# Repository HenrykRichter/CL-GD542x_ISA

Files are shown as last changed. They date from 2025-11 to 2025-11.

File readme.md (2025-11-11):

# Project  Cirrus Logic 542x ISA video card
This project is a fork of [542x_ISA](https://github.com/matt1187/542x_ISA) with some tweaks
and additions to the PCB. Notable changes compared to original project:
- made room on PCB to place the RAMs in SMT sockets
- added Monitor ID option (static or by attached Monitor)

Remaking from Cirrus Logic Databook  "CL-GD542X_Technical_Reference_Manual_Jan1994"
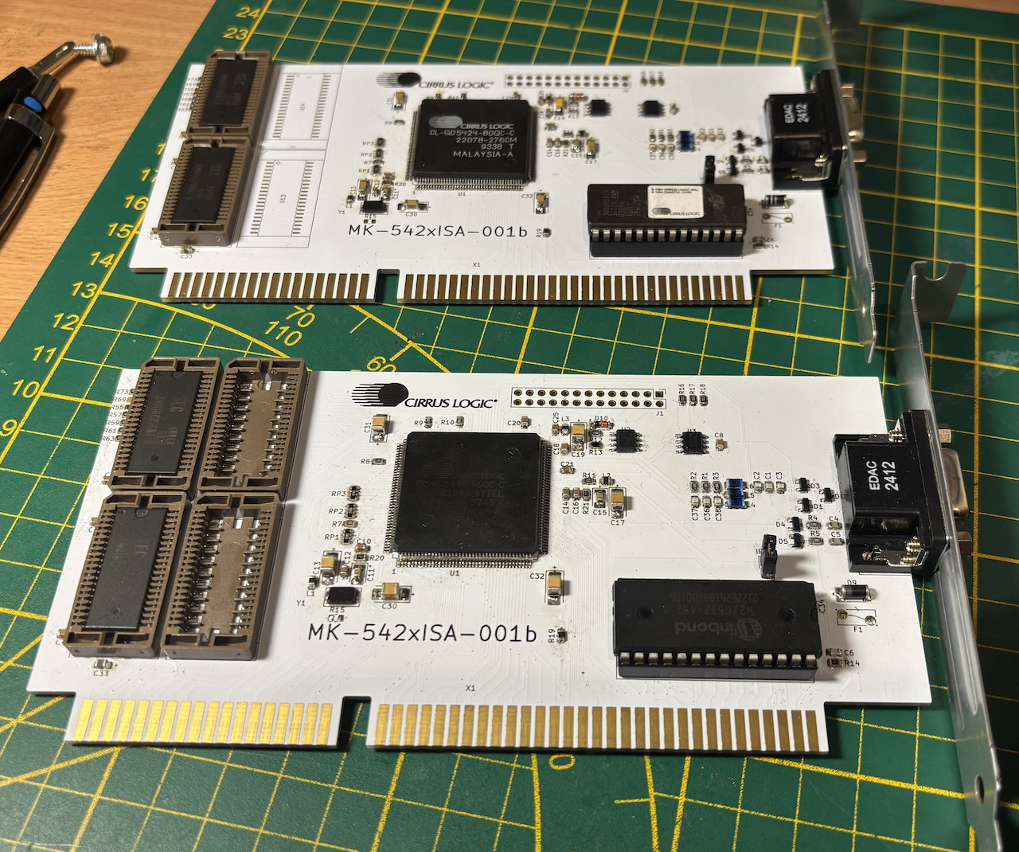
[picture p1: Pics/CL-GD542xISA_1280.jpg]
grafik


# PCB Revision History 
- forked from revision 001
- CL-GD542x-003 initial upload

# Features
- Cirrus Logic (CL-GD5422-5429) video chipset (5420 is not recommend for this design)
- good chocie video card for ISA bus platform
- up to 2 MB DRAM
- 80 MHz integrated RAMDAC (GD5429: 86 MHz )
- Win 3.1, Win9x, Win NT 3.51 & 4 driver available
- cheap GD542x VLB card as compoment donor.
- cheap 2 layer PCB layout 
  
# Issues 
- some 542x chip has vertical noise/stripe on TFT. (It is not pcb issuses)
- ROM from  cirrus logic video card as donor is not usable (hi/lo byte is seperated to difference address space, like address line "A0 and A14" is swapped)
- in some cases, the GD542x will boot in Monochrome mode. See [here](https://forum.vcfed.org/index.php?threads/trident-card-that-thinks-colour-monitor-is-monochrome.79054) for a fix.

# notes
- GD5420/22/24 support only 1 MB DRAM
- U11 & U12  is first 1 MB , U13/14 is seconds MB (except 5420, only U12 and U14 )
- all component with  followed ID is config strap (R55, R57, R59, R61, R63, R69, R73) place all **except** R55, R69
- R15 don't place, if you using interal XTAL oscillator (Y1/Y2 , C39,C40)
- Place only one of Y1/Y2 (either SMD **or** HC-49)
- SPI-EEPROM is optional.

# Bill of material

- see BOM subfolder for an iBOM file

# driver & ROM 
- [Cirrus Logic ROM generic for all GD542x,]

# License
The project is free for non-commercial reproduction. Do not sell it on Ebay or other platforms for profit. Do not make a closed source derivative. Share your experiences and ideas with the community.

This work is licensed under a [Creative Commons Attribution-NonCommercial-ShareAlike 4.0 International License][cc-by-nc-sa].

[][cc-by-nc-sa]

[cc-by-nc-sa]: http://creativecommons.org/licenses/by-nc-sa/4.0/
[cc-by-nc-sa-image]: https://licensebuttons.net/l/by-nc-sa/4.0/88x31.png

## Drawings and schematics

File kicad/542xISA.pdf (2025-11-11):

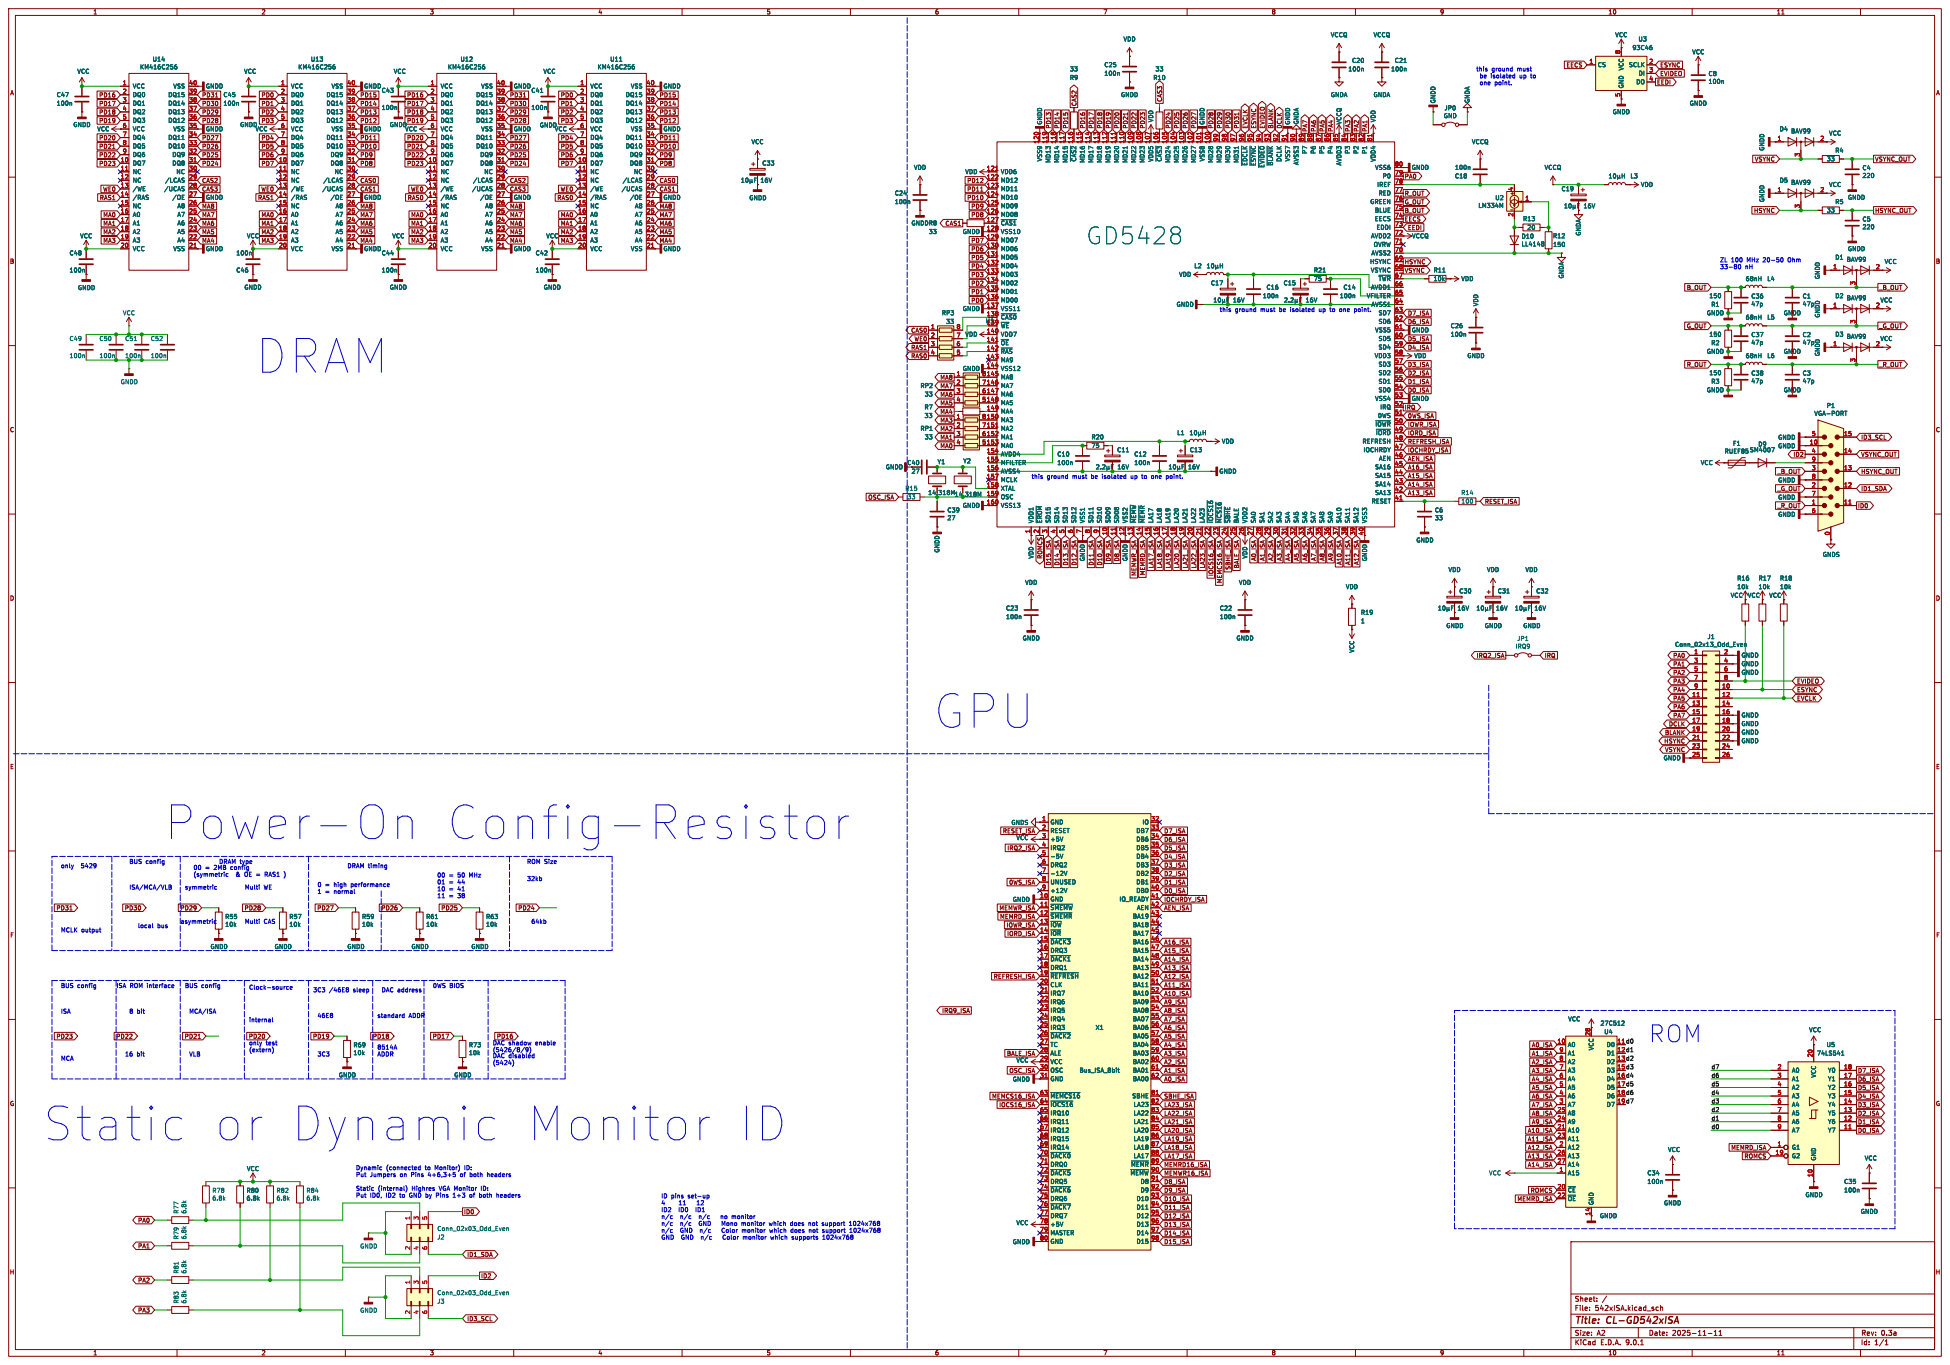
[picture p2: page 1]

U14 KM416C256 VCC 1 DQ0 2 DQ1 3 DQ2 4 DQ3 5 VCC 6 DQ4 7 DQ5 8 DQ6 9 DQ7 10 NC 11 NC 12

/OE 27 A8 26 A7 25 A6 24 A5 23 A4 22 VSS 21 U13 KM416C256 VCC GNDD
VCC

U13 KM416C256 VCC 1 DQ0 2 DQ1 3 DQ2 4 DQ3 5 VCC 6 DQ4 7 DQ5 8 DQ6 9 DQ7 10 NC 11 NC 12

U12 KM416C256 VCC 1 DQ0 2 DQ1 3 DQ2 4 DQ3 5 VCC 6 DQ4 7 DQ5 8 DQ6 9 DQ7 10 NC 11 NC 12
VCC 1 DQ0 2 DQ1 3 DQ2 4 DQ3 5 VCC 6 DQ4 7 DQ5 8 DQ6 9 DQ7 10 NC 11 NC 12

100nVCC GNDD GNDD GNDD GNDD

U11 KM416C256 VCC 1 DQ0 2 DQ1 3 DQ2 4 DQ3 5 VCC 6 DQ4 7 DQ5 8 DQ6 9 DQ7 10 NC 11 NC 12

þÿ10µF16V GNDD GNDD GNDD GNDD

9 MD19 112 SD09 10 MD20 111 SD08 11 MD21 110 VSS2 12 MD22 109 ~{MEMW} 13 MD23 108 ~{MEMR} 14 VDD5 107 LA17 15 ~{CAS3} 106 LA18 16 MD24 105 LA19 17 MD25 104 LA20 18 MD26 103 LA21 19 MD27 102 LA22 20 VSS8 101 LA23 21 MD28 100 ~{IOCS16} 22 MD29 99 ~{MCS16} 23 MD30 98 ~{SBHE} 24 MD31 97 BALE 25 ~{EDCLK}96 VDD2 26 ~{ESYNC}95 SA0 27 ~{EVIDEO}94 SA1 28 ~{BLANK}93 SA2 29 DCLK 92 SA3 30 VSS7 91 SA4 31 AVSS3 90 SA5 32 P7 89 SA6 33 P6 88 SA7 34 P5 87 SA8 35 P4 86 SA9 36 AVDD3 85 SA10 37 P3 84 SA11 38 P2 83 SA12 39 P1 82 VSS3 40 VDD4 81 VSS6

Static or Dynamic Monitor ID

ID pins set-up

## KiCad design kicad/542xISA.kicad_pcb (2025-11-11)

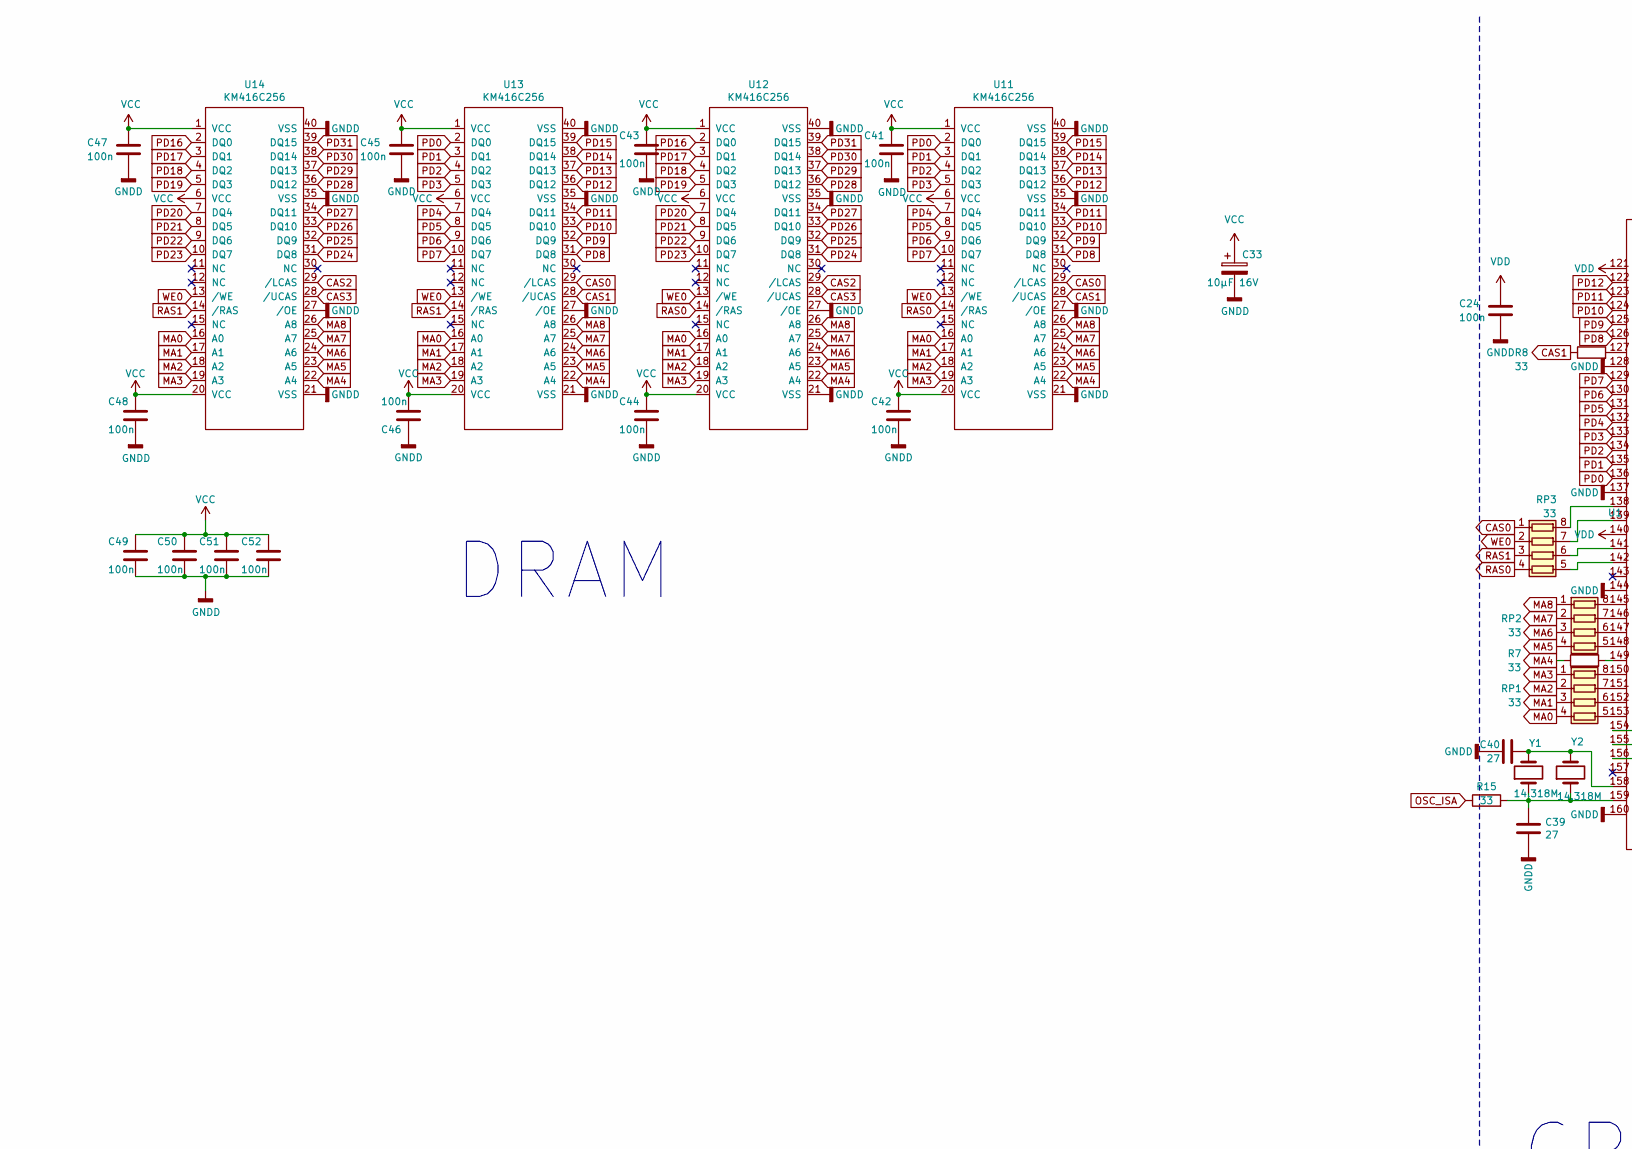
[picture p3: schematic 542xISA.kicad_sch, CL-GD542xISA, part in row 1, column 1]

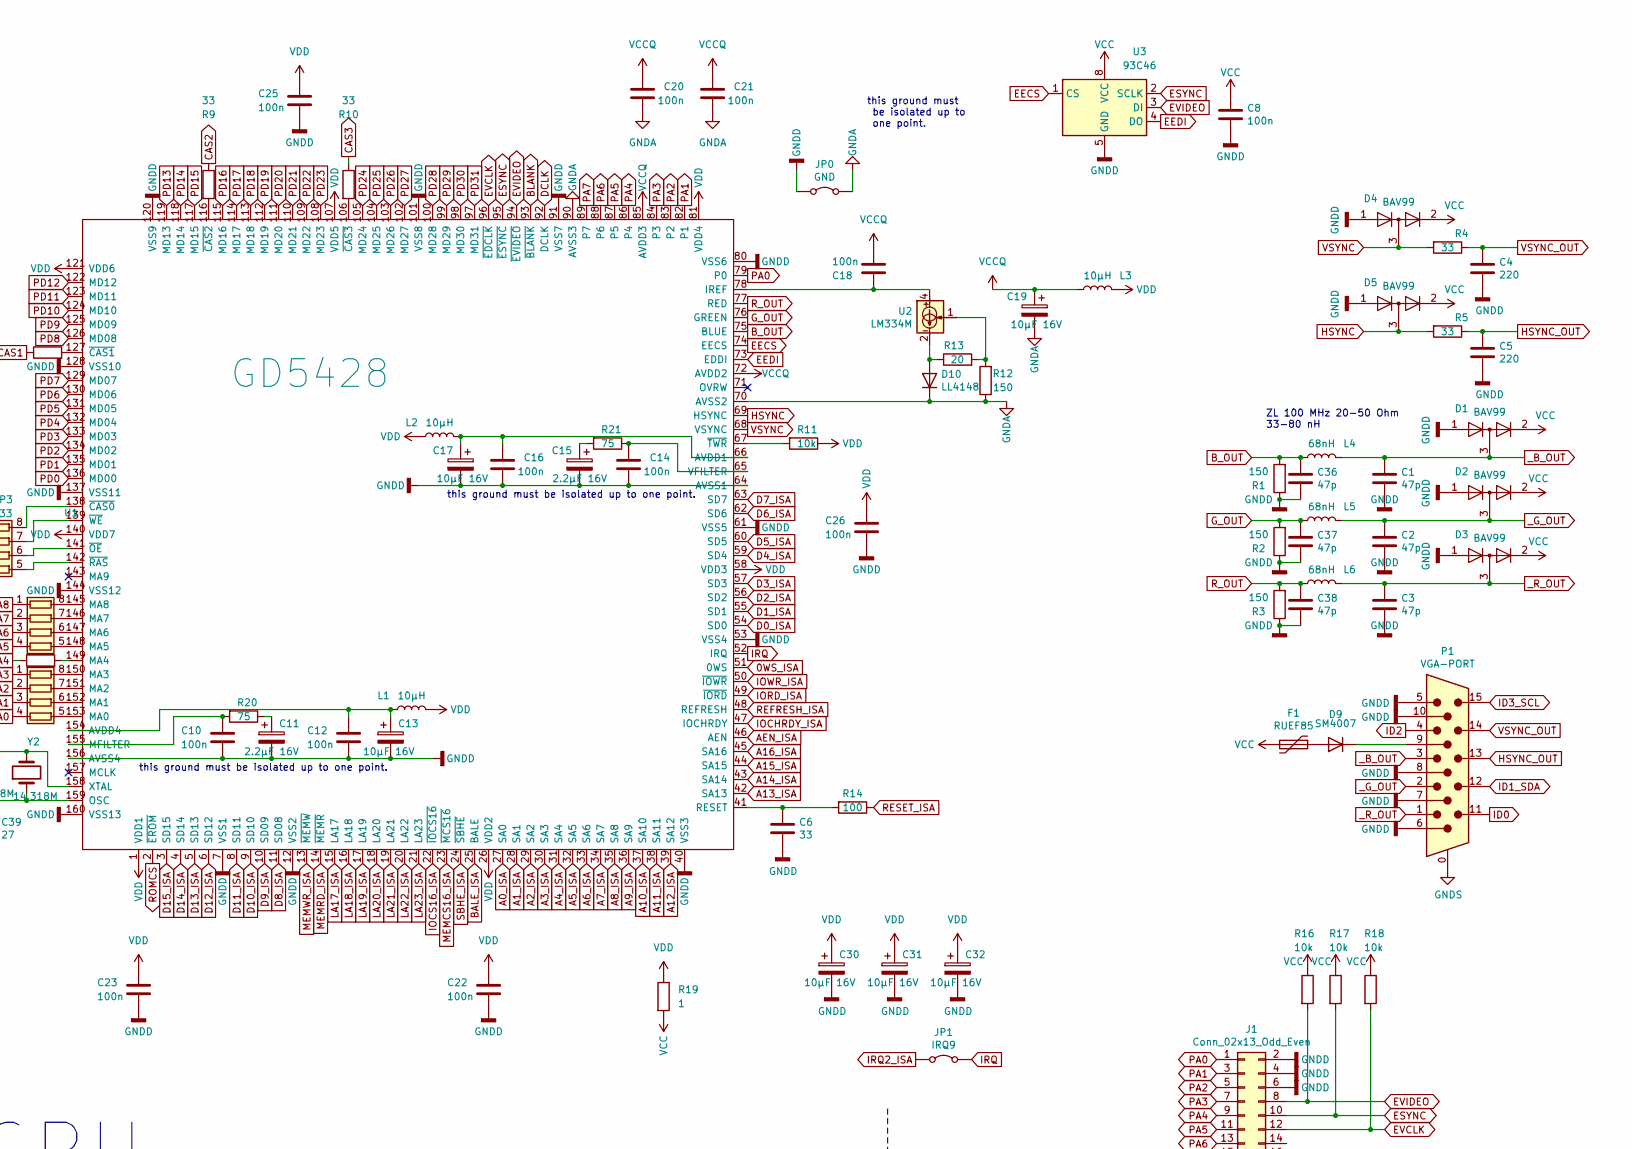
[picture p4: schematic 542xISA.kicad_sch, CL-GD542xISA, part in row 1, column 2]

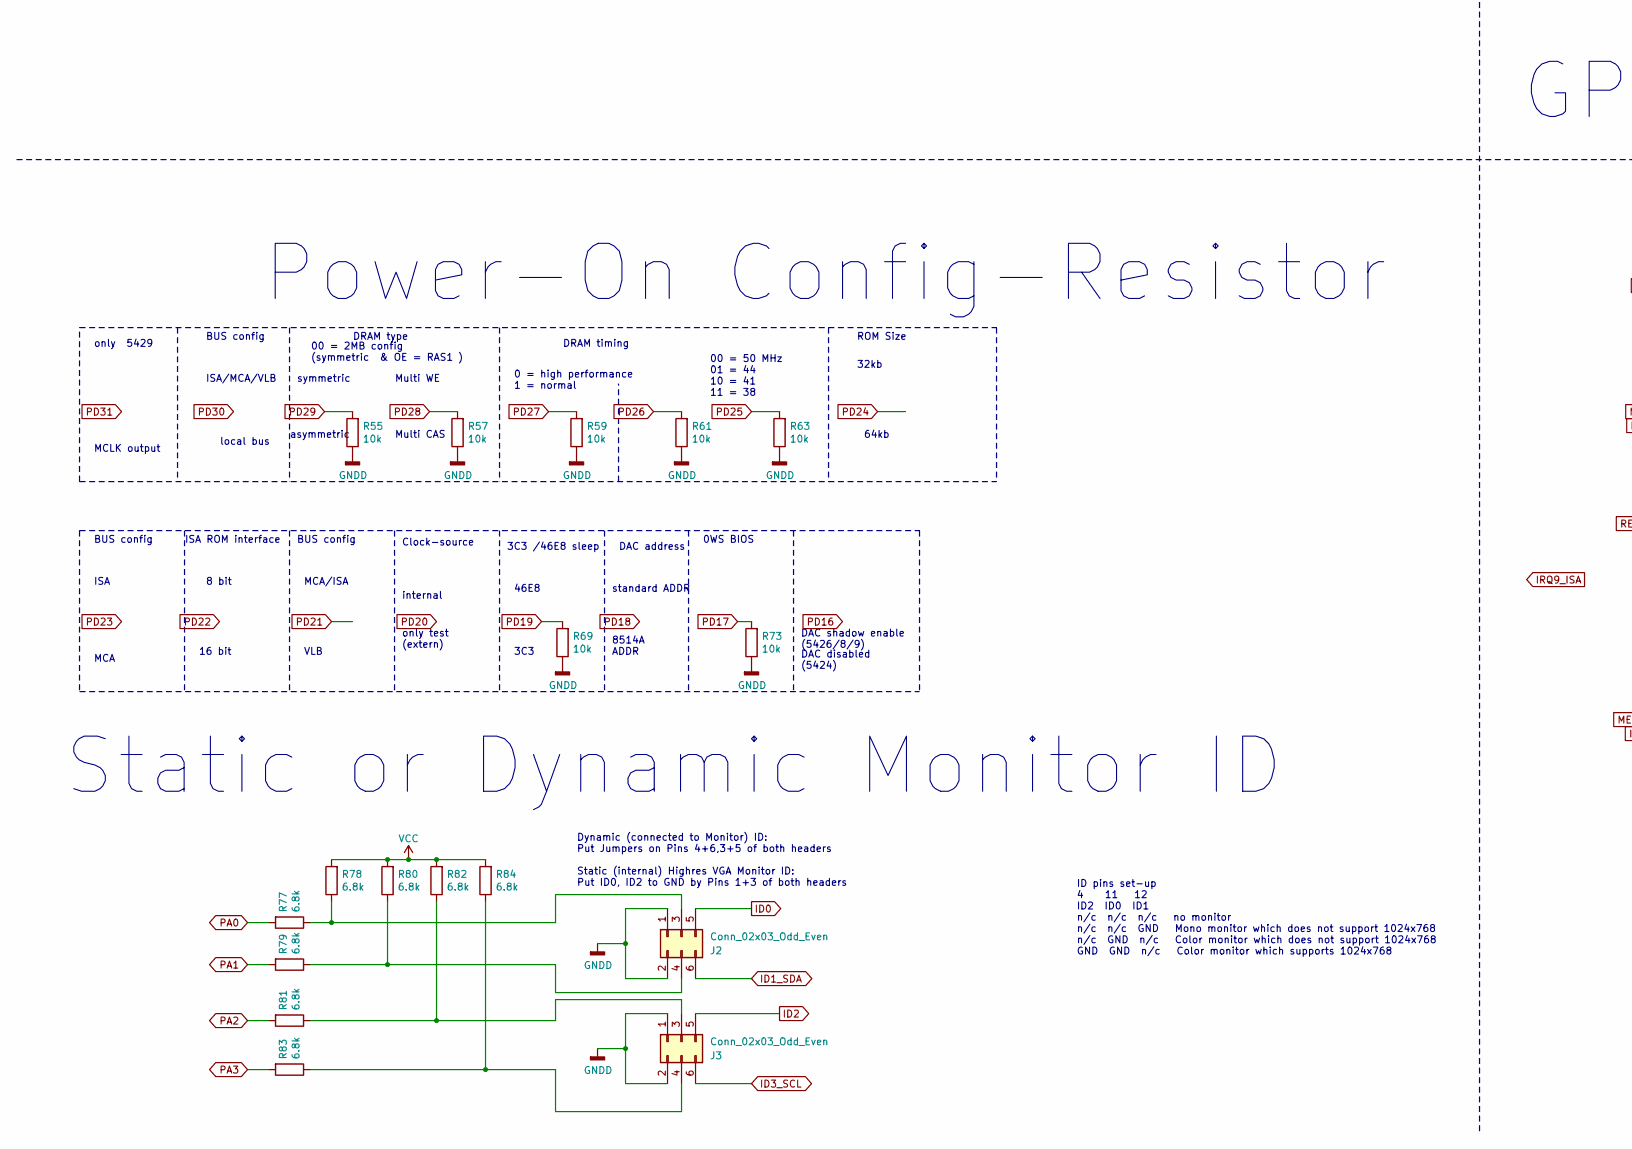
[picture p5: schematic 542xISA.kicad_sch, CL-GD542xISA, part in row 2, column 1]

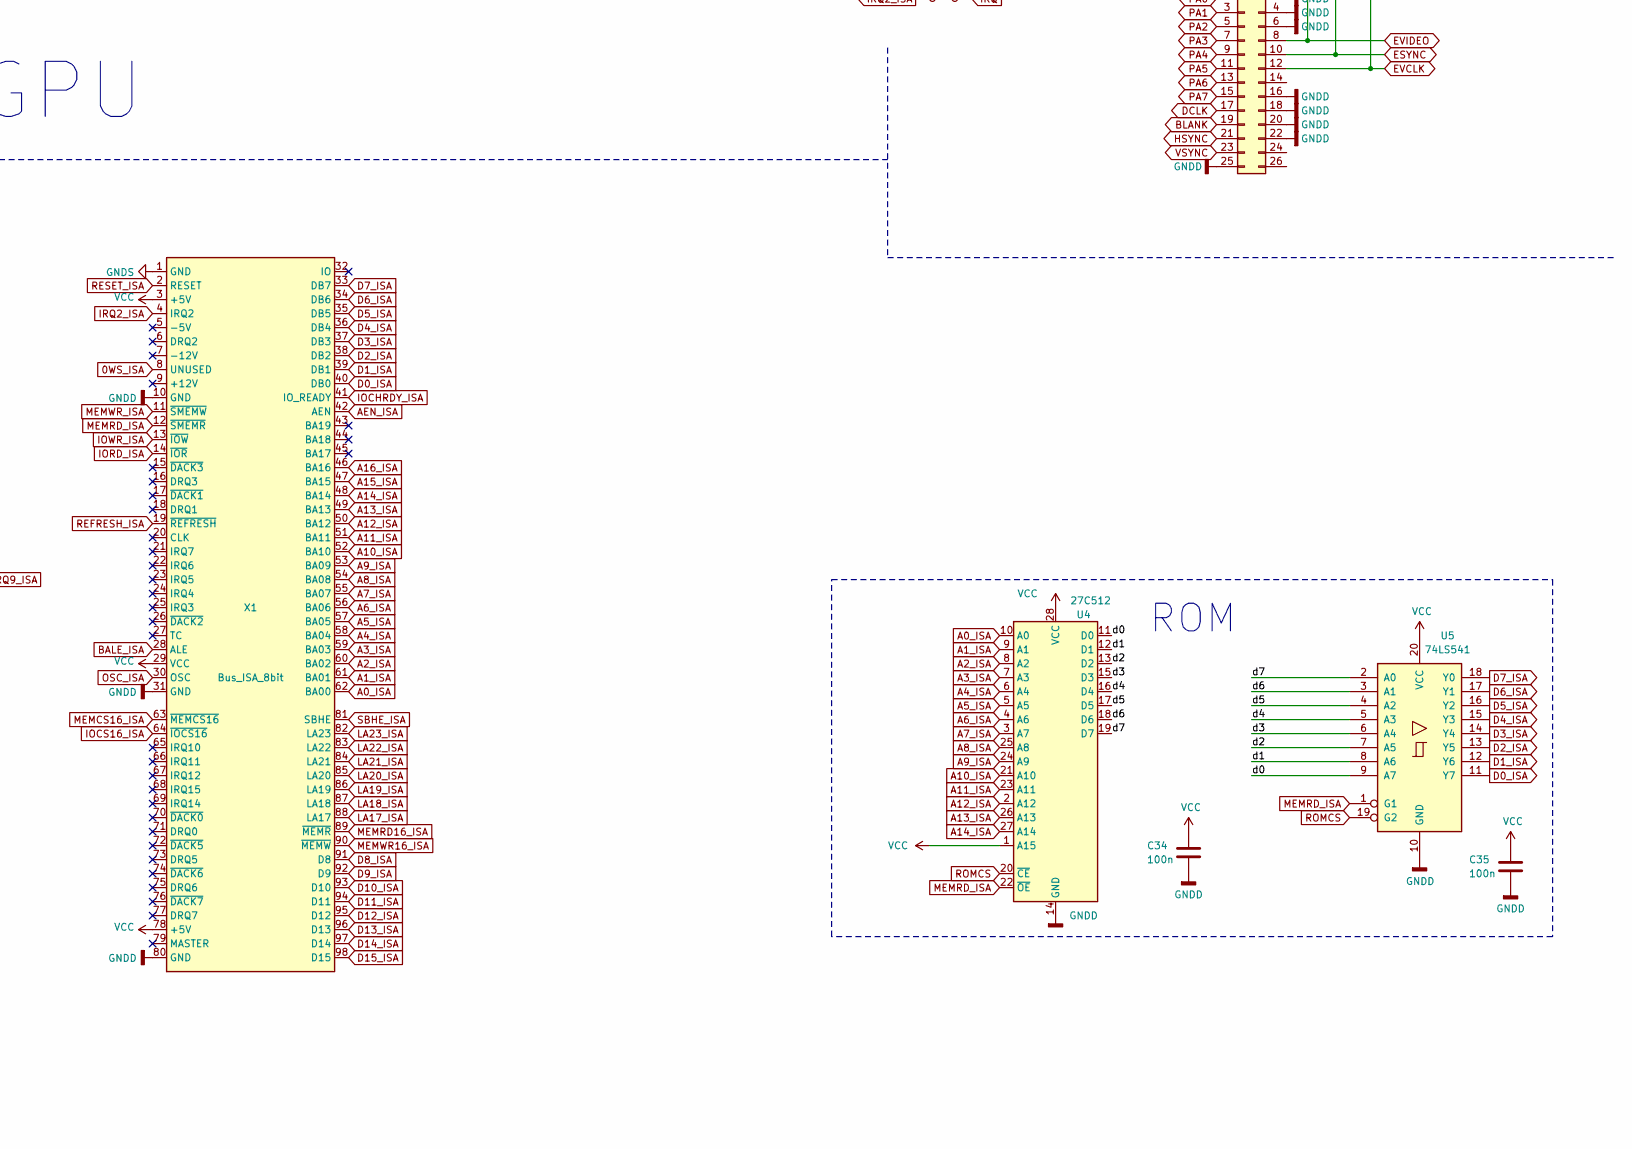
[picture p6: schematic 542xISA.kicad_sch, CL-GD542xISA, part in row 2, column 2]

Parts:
C1, C2, C3, C36, C37, C38: 47p; C_0805_2012Metric
C4, C5: 220; C_0805_2012Metric
C6: 33; C_0805_2012Metric
C8, C10, C12, C14, C16, C18, C20, C21, C22, C23, C24, C25, C26, C34, C35, C41, C42, C43, C44, C45, C46, C47, C48, C49, C50, C51, C52: 100n; C_0805_2012Metric
C11, C15: 2.2µF 16V; CP_EIA-3528-12_Kemet-T
C13, C17, C19, C31, C32: 10µF 16V; CP_EIA-6032-15_Kemet-U
C30, C33: 10µF 16V; C_0805_2012Metric_Pad1.18x1.45mm_HandSolder
C39, C40: 27; C_0805_2012Metric
D1, D2, D3, D4, D5: BAV99; SOT-23
D9: SM4007; D_MELF
D10: LL4148; D_MiniMELF
F1: RUEF85; Fuse_Bourns_MF-RG300
J1: Conn_02x13_Odd_Even; PinHeader_2x13_P2.54mm_Vertical
J2, J3: Conn_02x03_Odd_Even; PinHeader_2x03_P2.54mm_Vertical
JP0: GND; SolderJumper-2_P1.3mm_Bridged2Bar_Pad1.0x1.5mm
JP1: IRQ9; PinHeader_1x02_P2.54mm_Vertical
L1, L2, L3: 10µH; L_0805_2012Metric
L4, L5, L6: 68nH; L_1206_3216Metric
P1: VGA-PORT; DSUB-15-HD_Female_Horizontal_P2.29x1.98mm_EdgePinOffset8.35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
R1, R2, R3, R12: 150; R_0805_2012Metric
R4, R5, R7, R8, R9, R10, R15: 33; R_0805_2012Metric
R11, R16, R17, R18, R55, R57, R59, R61, R63, R69, R73: 10k; R_0805_2012Metric
R13: 20; R_0805_2012Metric
R14: 100; R_0805_2012Metric
R19: 1; R_0805_2012Metric
R20, R21: 75; R_0805_2012Metric
R77, R78, R79, R80, R81, R82, R83, R84: 6.8k; R_0805_2012Metric
RP1, RP2, RP3: 33; R_Array_Concave_4x0603
U1: GD5428; PQFP-160_28x28mm_P0.65mm
U2: LM334M; SOIC-8_3.9x4.9mm_P1.27mm
U3: 93C46; SOIC-8_3.9x4.9mm_P1.27mm
U4: 27C512; DIP-28_W15.24mm_Socket
U5: 74LS541; SOIC-20W_7.5x12.8mm_P1.27mm
U11, U12, U13, U14: KM416C256; SOJ-40-Socket
X1: Bus_ISA_8bit; BUS_AT
Y1: 14.318M; Crystal_SMD_0603-2Pin_6.0x3.5mm
Y2: 14.318M; Crystal_HC49-U_Vertical

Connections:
0WS_ISA: U1.51 (0WS), X1.8 (UNUSED)
/d0: U4.11 (D0), U5.9 (A7)
/d1: U4.12 (D1), U5.8 (A6)
/d2: U4.13 (D2), U5.7 (A5)
/d3: U4.15 (D3), U5.6 (A4)
/d4: U4.16 (D4), U5.5 (A3)
/d5: U4.17 (D5), U5.4 (A2)
/d6: U4.18 (D6), U5.3 (A1)
/d7: U4.19 (D7), U5.2 (A0)
A0_ISA: U1.27 (SA0), U4.10 (A0), X1.62 (BA00)
A1_ISA: U1.28 (SA1), U4.9 (A1), X1.61 (BA01)
A2_ISA: U1.29 (SA2), U4.8 (A2), X1.60 (BA02)
A3_ISA: U1.30 (SA3), U4.7 (A3), X1.59 (BA03)
A4_ISA: U1.31 (SA4), U4.6 (A4), X1.58 (BA04)
A5_ISA: U1.32 (SA5), U4.5 (A5), X1.57 (BA05)
A6_ISA: U1.33 (SA6), U4.4 (A6), X1.56 (BA06)
A7_ISA: U1.34 (SA7), U4.3 (A7), X1.55 (BA07)
A8_ISA: U1.35 (SA8), U4.25 (A8), X1.54 (BA08)
A9_ISA: U1.36 (SA9), U4.24 (A9), X1.53 (BA09)
A10_ISA: U1.37 (SA10), U4.21 (A10), X1.52 (BA10)
A11_ISA: U1.38 (SA11), U4.23 (A11), X1.51 (BA11)
A12_ISA: U1.39 (SA12), U4.2 (A12), X1.50 (BA12)
A13_ISA: U1.42 (SA13), U4.26 (A13), X1.49 (BA13)
A14_ISA: U1.43 (SA14), U4.27 (A14), X1.48 (BA14)
A15_ISA: U1.44 (SA15), X1.47 (BA15)
A16_ISA: U1.45 (SA16), X1.46 (BA16)
AEN_ISA: U1.46 (AEN), X1.42 (AEN)
BALE_ISA: U1.25 (BALE), X1.28 (ALE)
BLANK: J1.19, U1.93 (~BLANK)
B_OUT: C36.1, L4.2, R1.2, U1.75 (BLUE)
CAS0: RP3.1 (R1.1), U11.29 (/LCAS), U13.29 (/LCAS)
CAS1: R8.1, U11.28 (/UCAS), U13.28 (/UCAS)
CAS2: R9.1, U12.29 (/LCAS), U14.29 (/LCAS)
CAS3: R10.1, U12.28 (/UCAS), U14.28 (/UCAS)
D0_ISA: U1.54 (SD0), U5.11 (Y7), X1.40 (DB0)
D1_ISA: U1.55 (SD1), U5.12 (Y6), X1.39 (DB1)
D2_ISA: U1.56 (SD2), U5.13 (Y5), X1.38 (DB2)
D3_ISA: U1.57 (SD3), U5.14 (Y4), X1.37 (DB3)
D4_ISA: U1.59 (SD4), U5.15 (Y3), X1.36 (DB4)
D5_ISA: U1.60 (SD5), U5.16 (Y2), X1.35 (DB5)
D6_ISA: U1.62 (SD6), U5.17 (Y1), X1.34 (DB6)
D7_ISA: U1.63 (SD7), U5.18 (Y0), X1.33 (DB7)
D8_ISA: U1.11 (SD08), X1.91 (D8)
D9_ISA: U1.10 (SD09), X1.92 (D9)
D10_ISA: U1.9 (SD10), X1.93 (D10)
D11_ISA: U1.8 (SD11), X1.94 (D11)
D12_ISA: U1.6 (SD12), X1.95 (D12)
D13_ISA: U1.5 (SD13), X1.96 (D13)
D14_ISA: U1.4 (SD14), X1.97 (D14)
D15_ISA: U1.3 (SD15), X1.98 (D15)
DCLK: J1.17, U1.92 (DCLK)
EECS: U1.74 (EECS), U3.1 (CS)
EEDI: U1.73 (EDDI), U3.4 (DO)
ESYNC: J1.10, R17.2, U1.95 (~ESYNC), U3.2 (SCLK)
EVCLK: J1.12, R18.2, U1.96 (~EDCLK)
EVIDEO: J1.8, R16.2, U1.94 (~EVIDEO), U3.3 (DI)
GNDA: C19.2, C20.2, C21.2, D10.1 (K), JP0.2 (B), R12.1, U1.70 (AVSS2), U1.90 (AVSS3)
GNDD: C1.2, C2.2, C3.2, C4.2, C5.2, C6.2, C8.2, C10.2, C11.2, C12.2, C13.2, C14.2, C15.2, C16.2, C17.2, C22.2, C23.2, C24.2, C25.2, C26.2, C30.2, C31.2, C32.2, C33.2, C34.2, C35.2, C36.2, C37.2, C38.2, C39.2, C40.1, C41.2, C42.2, C43.2, C44.2, C45.2, C46.2, C47.2, C48.2, C49.2, C50.2, C51.2, C52.2, D1.1 (K), D2.1 (K), D3.1 (K), D4.1 (K), D5.1 (K), J1.2, J1.4, J1.6, J1.16, J1.18, J1.20, J1.22, J1.25, J2.1, J2.2, J3.1, J3.2, JP0.1 (A), P1.5, P1.6, P1.7, P1.8, P1.10, R1.1, R2.1, R3.1, R55.1, R57.1, R59.1, R61.1, R63.1, R69.1, R73.1, U1.7 (VSS1), U1.12 (VSS2), U1.40 (VSS3), U1.53 (VSS4), U1.61 (VSS5), U1.64 (AVSS1), U1.80 (VSS6), U1.91 (VSS7), U1.101 (VSS8), U1.120 (VSS9), U1.128 (VSS10), U1.137 (VSS11), U1.144 (VSS12), U1.156 (AVSS4), U1.160 (VSS13), U3.5 (GND), U4.14 (GND), U5.10 (GND), U11.21 (VSS), U11.27 (/OE), U11.35 (VSS), U11.40 (VSS), U12.21 (VSS), U12.27 (/OE), U12.35 (VSS), U12.40 (VSS), U13.21 (VSS), U13.27 (/OE), U13.35 (VSS), U13.40 (VSS), U14.21 (VSS), U14.27 (/OE), U14.35 (VSS), U14.40 (VSS), X1.10 (GND), X1.31 (GND), X1.80 (GND)
GNDS: P1.0, X1.1 (GND)
G_OUT: C37.1, L5.2, R2.2, U1.76 (GREEN)
HSYNC: D5.3 (K), J1.21, R5.2, U1.69 (HSYNC)
HSYNC_OUT: C5.1, P1.13, R5.1
ID0: J2.5, P1.11
ID1_SDA: J2.6, P1.12
ID2: J3.5, P1.4
ID3_SCL: J3.6, P1.15
IOCHRDY_ISA: U1.47 (IOCHRDY), X1.41 (IO_READY)
IOCS16_ISA: U1.22 (~IOCS16), X1.64 (~IOCS16)
IORD_ISA: U1.49 (~IORD), X1.14 (~IOR)
IOWR_ISA: U1.50 (~IOWR), X1.13 (~IOW)
IRQ: JP1.2 (B), U1.52 (IRQ)
IRQ2_ISA: JP1.1 (A), X1.4 (IRQ2)
LA17_ISA: U1.15 (LA17), X1.88 (LA17)
LA18_ISA: U1.16 (LA18), X1.87 (LA18)
LA19_ISA: U1.17 (LA19), X1.86 (LA19)
LA20_ISA: U1.18 (LA20), X1.85 (LA20)
LA21_ISA: U1.19 (LA21), X1.84 (LA21)
LA22_ISA: U1.20 (LA22), X1.83 (LA22)
LA23_ISA: U1.21 (LA23), X1.82 (LA23)
MA0: RP1.4 (R4.1), U11.16 (A0), U12.16 (A0), U13.16 (A0), U14.16 (A0)
MA1: RP1.3 (R3.1), U11.17 (A1), U12.17 (A1), U13.17 (A1), U14.17 (A1)
MA2: RP1.2 (R2.1), U11.18 (A2), U12.18 (A2), U13.18 (A2), U14.18 (A2)
MA3: RP1.1 (R1.1), U11.19 (A3), U12.19 (A3), U13.19 (A3), U14.19 (A3)
MA4: R7.1, U11.22 (A4), U12.22 (A4), U13.22 (A4), U14.22 (A4)
MA5: RP2.4 (R4.1), U11.23 (A5), U12.23 (A5), U13.23 (A5), U14.23 (A5)
MA6: RP2.3 (R3.1), U11.24 (A6), U12.24 (A6), U13.24 (A6), U14.24 (A6)
MA7: RP2.2 (R2.1), U11.25 (A7), U12.25 (A7), U13.25 (A7), U14.25 (A7)
MA8: RP2.1 (R1.1), U11.26 (A8), U12.26 (A8), U13.26 (A8), U14.26 (A8)
MEMCS16_ISA: U1.23 (~MCS16), X1.63 (~MEMCS16)
MEMRD16_ISA: X1.89 (~MEMR)
MEMRD_ISA: U1.14 (~MEMR), U4.22 (~OE), U5.1 (G1), X1.12 (~SMEMR)
MEMWR16_ISA: X1.90 (~MEMW)
MEMWR_ISA: U1.13 (~MEMW), X1.11 (~SMEMW)
unnamed: C11.1, R20.1
unnamed: C15.1, R21.2
unnamed: D9.2 (A), F1.1
unnamed: D9.1 (K), P1.9
unnamed: D10.2 (A), R13.1, U2.2, U2.3, U2.6, U2.7
unnamed: J2.3, R77.1, R78.1
unnamed: J2.4, R79.1, R80.1
unnamed: J3.3, R81.1, R82.1
unnamed: J3.4, R83.1, R84.1
unnamed: R12.2, R13.2, U2.1
unnamed: RP1.8 (R1.2), U1.150 (MA3)
unnamed: RP1.7 (R2.2), U1.151 (MA2)
unnamed: RP1.6 (R3.2), U1.152 (MA1)
unnamed: RP1.5 (R4.2), U1.153 (MA0)
unnamed: RP2.8 (R1.2), U1.145 (MA8)
unnamed: RP2.7 (R2.2), U1.146 (MA7)
unnamed: RP2.6 (R3.2), U1.147 (MA6)
unnamed: RP2.5 (R4.2), U1.148 (MA5)
unnamed: RP3.8 (R1.2), U1.138 (~CAS0)
unnamed: RP3.7 (R2.2), U1.139 (~WE)
unnamed: RP3.6 (R3.2), U1.141 (~OE)
unnamed: RP3.5 (R4.2), U1.142 (~RAS)
unnamed: C16.1, C17.1, L2.2, U1.66 (AVDD1)
unnamed: C12.1, C13.1, L1.1, U1.154 (AVDD4)
unnamed: C18.1, U1.78 (IREF), U2.4
unnamed: R7.2, U1.149 (MA4)
unnamed: C10.1, R20.2, U1.155 (MFILTER)
unnamed: C39.1, R15.2, U1.159 (OSC), Y1.1, Y2.1
unnamed: C6.1, R14.2, U1.41 (RESET)
unnamed: C14.1, R21.1, U1.65 (VFILTER)
unnamed: C40.2, U1.158 (XTAL), Y1.2, Y2.2
unnamed: R8.2, U1.127 (~CAS1)
unnamed: R9.2, U1.116 (~CAS2)
unnamed: R10.2, U1.106 (~CAS3)
unnamed: R11.2, U1.67 (~TWR)
OSC_ISA: R15.1, X1.30 (OSC)
PA0: J1.1, R77.2, U1.79 (P0)
PA1: J1.3, R79.2, U1.82 (P1)
PA2: J1.5, R81.2, U1.83 (P2)
PA3: J1.7, R83.2, U1.84 (P3)
PA4: J1.9, U1.86 (P4)
PA5: J1.11, U1.87 (P5)
PA6: J1.13, U1.88 (P6)
PA7: J1.15, U1.89 (P7)
PD0: U1.136 (MD00), U11.2 (DQ0), U13.2 (DQ0)
PD1: U1.135 (MD01), U11.3 (DQ1), U13.3 (DQ1)
PD2: U1.134 (MD02), U11.4 (DQ2), U13.4 (DQ2)
PD3: U1.133 (MD03), U11.5 (DQ3), U13.5 (DQ3)
PD4: U1.132 (MD04), U11.7 (DQ4), U13.7 (DQ4)
PD5: U1.131 (MD05), U11.8 (DQ5), U13.8 (DQ5)
PD6: U1.130 (MD06), U11.9 (DQ6), U13.9 (DQ6)
PD7: U1.129 (MD07), U11.10 (DQ7), U13.10 (DQ7)
PD8: U1.126 (MD08), U11.31 (DQ8), U13.31 (DQ8)
PD9: U1.125 (MD09), U11.32 (DQ9), U13.32 (DQ9)
PD10: U1.124 (MD10), U11.33 (DQ10), U13.33 (DQ10)
PD11: U1.123 (MD11), U11.34 (DQ11), U13.34 (DQ11)
PD12: U1.122 (MD12), U11.36 (DQ12), U13.36 (DQ12)
PD13: U1.119 (MD13), U11.37 (DQ13), U13.37 (DQ13)
PD14: U1.118 (MD14), U11.38 (DQ14), U13.38 (DQ14)
PD15: U1.117 (MD15), U11.39 (DQ15), U13.39 (DQ15)
PD16: U1.115 (MD16), U12.2 (DQ0), U14.2 (DQ0)
PD17: R73.2, U1.114 (MD17), U12.3 (DQ1), U14.3 (DQ1)
PD18: U1.113 (MD18), U12.4 (DQ2), U14.4 (DQ2)
PD19: R69.2, U1.112 (MD19), U12.5 (DQ3), U14.5 (DQ3)
PD20: U1.111 (MD20), U12.7 (DQ4), U14.7 (DQ4)
PD21: U1.110 (MD21), U12.8 (DQ5), U14.8 (DQ5)
PD22: U1.109 (MD22), U12.9 (DQ6), U14.9 (DQ6)
PD23: U1.108 (MD23), U12.10 (DQ7), U14.10 (DQ7)
PD24: U1.105 (MD24), U12.31 (DQ8), U14.31 (DQ8)
PD25: R63.2, U1.104 (MD25), U12.32 (DQ9), U14.32 (DQ9)
PD26: R61.2, U1.103 (MD26), U12.33 (DQ10), U14.33 (DQ10)
PD27: R59.2, U1.102 (MD27), U12.34 (DQ11), U14.34 (DQ11)
PD28: R57.2, U1.100 (MD28), U12.36 (DQ12), U14.36 (DQ12)
PD29: R55.2, U1.99 (MD29), U12.37 (DQ13), U14.37 (DQ13)
PD30: U1.98 (MD30), U12.38 (DQ14), U14.38 (DQ14)
PD31: U1.97 (MD31), U12.39 (DQ15), U14.39 (DQ15)
RAS0: RP3.4 (R4.1), U11.14 (/RAS), U12.14 (/RAS)
RAS1: RP3.3 (R3.1), U13.14 (/RAS), U14.14 (/RAS)
REFRESH_ISA: U1.48 (REFRESH), X1.19 (~REFRESH)
RESET_ISA: R14.1, X1.2 (RESET)
ROMCS: U1.2 (~EROM), U4.20 (~CE), U5.19 (G2)
R_OUT: C38.1, L6.2, R3.2, U1.77 (RED)
SBHE_ISA: U1.24 (~SBHE), X1.81 (SBHE)
VCC: C8.1, C33.1, C34.1, C35.1, C41.1, C42.1, C43.1, C44.1, C45.1, C46.1, C47.1, C48.1, C49.1, C50.1, C51.1, C52.1, D1.2 (A), D2.2 (A), D3.2 (A), D4.2 (A), D5.2 (A), F1.2, R16.1, R17.1, R18.1, R19.2, R78.2, R80.2, R82.2, R84.2, U3.8 (VCC), U4.1 (A15), U4.28 (VCC), U5.20 (VCC), U11.1 (VCC), U11.6 (VCC), U11.20 (VCC), U12.1 (VCC), U12.6 (VCC), U12.20 (VCC), U13.1 (VCC), U13.6 (VCC), U13.20 (VCC), U14.1 (VCC), U14.6 (VCC), U14.20 (VCC), X1.3 (+5V), X1.29 (VCC), X1.78 (+5V)
VCCQ: C18.2, C19.1, C20.1, C21.1, L3.2, U1.72 (AVDD2), U1.85 (AVDD3)
VDD: C22.1, C23.1, C24.1, C25.1, C26.1, C30.1, C31.1, C32.1, L1.2, L2.1, L3.1, R11.1, R19.1, U1.1 (VDD1), U1.26 (VDD2), U1.58 (VDD3), U1.81 (VDD4), U1.107 (VDD5), U1.121 (VDD6), U1.140 (VDD7)
VSYNC: D4.3 (K), J1.23, R4.2, U1.68 (VSYNC)
VSYNC_OUT: C4.1, P1.14, R4.1
WE0: RP3.2 (R2.1), U11.13 (/WE), U12.13 (/WE), U13.13 (/WE), U14.13 (/WE)
_B_OUT: C1.1, D1.3 (K), L4.1, P1.3
_G_OUT: C2.1, D2.3 (K), L5.1, P1.2
_R_OUT: C3.1, D3.3 (K), L6.1, P1.1

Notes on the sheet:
asymmetric
BUS config
this ground must be isolated up to one point.
VLB
standard ADDR
DRAM timing
MCLK output
00 = 2MB config (symmetric & OE = RAS1 )
8 bit
DAC disabled (5424)
Dynamic (connected to Monitor) ID: Put Jumpers on Pins 4+6,3+5 of both headers Static (internal) Highres VGA Monitor ID: Put ID0, ID2 to GND by Pins 1+3 of both headers
only test (extern)
ROM Size
DAC shadow enable (5426/8/9)
0 = high performance 1 = normal
32kb
46E8
this ground must be isolated up to one point.
ISA/MCA/VLB
ISA ROM interface
Multi WE
Clock-source
ROM
3C3 /46E8 sleep
ID pins set-up 4 11 12 ID2 ID0 ID1 n/c n/c n/c no monitor n/c n/c GND Mono monitor which does not support 1024x768 n/c GND n/c Color monitor which does not support 1024x768 GND GND n/c Color monitor which supports 1024x768
Static or Dynamic Monitor ID
DRAM type
ZL 100 MHz 20-50 Ohm 33-80 nH
DRAM
only 5429
MCA
symmetric
local bus
GPU
00 = 50 MHz 01 = 44 10 = 41 11 = 38
0WS BIOS
64kb
DAC address
internal
16 bit

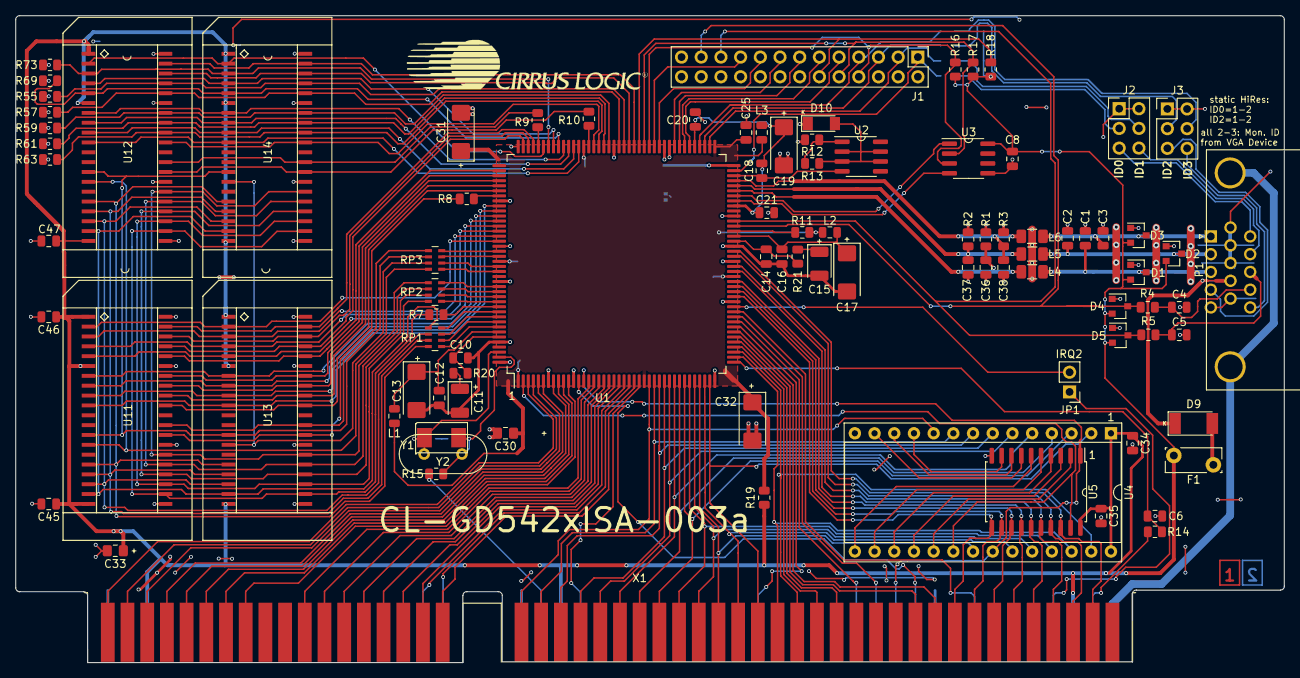
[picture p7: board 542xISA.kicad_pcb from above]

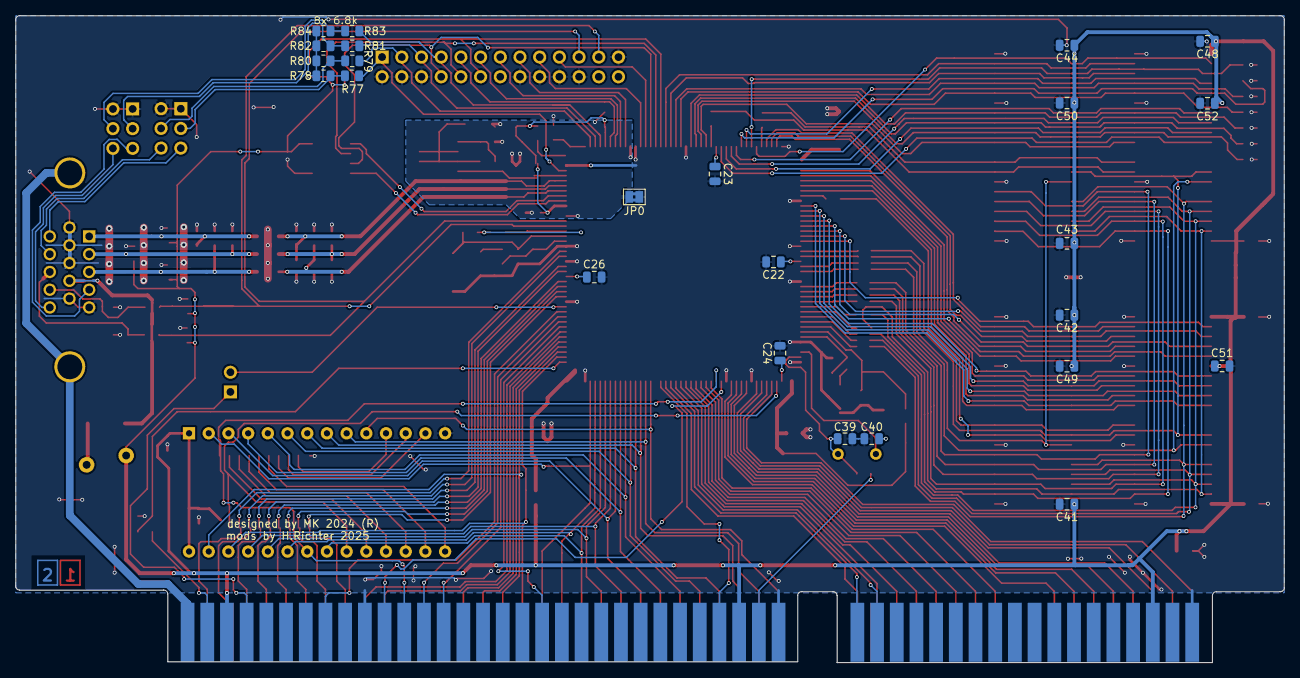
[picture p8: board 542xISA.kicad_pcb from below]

Board: 2 copper layers, 163.6 x 83.4 mm, 118 parts (24 on the bottom side), 183 nets.

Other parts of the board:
Cirrus1: (no value)
